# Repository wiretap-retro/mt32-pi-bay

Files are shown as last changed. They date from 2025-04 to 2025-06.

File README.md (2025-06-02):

# mt32-pi-bay
A 5.25" bay panel overlay to control the mt32-pi. 
\
\
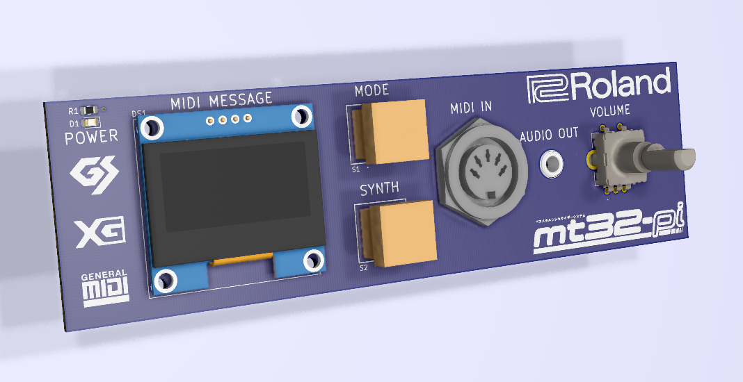
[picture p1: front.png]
front


## Info
The core project design is attributed to Dale Whinham and his awesome mt32-pi project. Repo link: https://github.com/dwhinham/mt32-pi
\
\
This PCB I designed is a 5.25" bay front panel overlay to control the mt32-pi system. It features a power LED, 1.3" OLED, two push buttons, rotary encoder knob, MIDI input jack, and a 3.5mm headphone output jack.
\
\
I have included the full KiCad project along with the Mouser Cart, BOM, and Gerber files for ease of upload.
\
\
This is designed for use with my mt32-pi-zero-breakout project found here: https://github.com/wiretap-retro/mt32-pi-zero-breakout/
\
\
Both the breakout board and 5.25 bay are 100% tested and functional. 

## Parts
The parts in the BOM and Mouser Cart are for building a blue illuminated unit. You can choose other color illuminated components, however you will need to change the resistors to different values since the forward voltage of the LED will be different. Regardless, you should calculate the LED resistors for your desired current/brightness based on the product datasheet curves. The BOM as-is makes the buttons look great, however the power LED is a little bright and could use a slightly higher resistor value.
\
\
Please read the original mt32-pi repository linked in the information section for compatibility of parts if you fork the design or deviate from the chosen parts.

## Assembly
- First solder all the components to the board. To keep the screen low-profile, no pin header socket should be used.
- Solder your wire pigtails to the DIN connector and 3.5mm connector.
- Next, insert the DIN and 3.5mm receptacles into the panel and secure them with the lock nuts.
- Test fit the assembled PCB to the StarTech bay adapter. There are going to be slight interferences from the solder fillets sticking out. Trim the bay adapter with a rotary tool or your preferred cutting method. 
- Clean the StarTech bay panel face and rear side of the PCB with isopropyl alcohol.
- Smear a thin layer of silicone caulk on the StarTech bay panel face.
- Set the PCB onto the bay panel face and apply a small amount of force to allow the caulk to spread and adhere. Shift it around to align it with the edges if necessary. 
- Allow a dry time of 24hrs so the PCB fully cures to the bay adapter face.
- Mount your mt32-pi into the StarTech bay adapter and connect the 2.54mm pitch DuPont connectors to the panel header.

## 1U Case and Parts (optional)
- Athena Power 1U Short-Depth Server Chassis with 5.25" Bay - http://athenapower.com/product/ipc-rackmount-chassis/1u-itx-rackmount/rm-1uc138 (other 1U models may work as well)
- Canakit 3.5A Power Supply - https://www.amazon.com/dp/B07TYQRXTK
- IEC320 Power Connector - https://www.amazon.com/dp/B085BQ3NWD
- SPST Blue Rocker Switch - https://www.amazon.com/dp/B08YN7Z9Y3
- 5V Blue Fans - https://www.amazon.com/dp/B084RCBSBX
- USB to 5V Fan Adapter - https://www.amazon.com/dp/B09HGLN7CX
- USB to DuPont Interal Connectors - https://www.ebay.com/itm/391937393112
- 3D Printable IEC to Flex-ATX adapter - https://www.thingiverse.com/thing:7041659
- 3D Printable Canakit Power Supply Enclosure - https://www.thingiverse.com/thing:7052683

## Finished Product

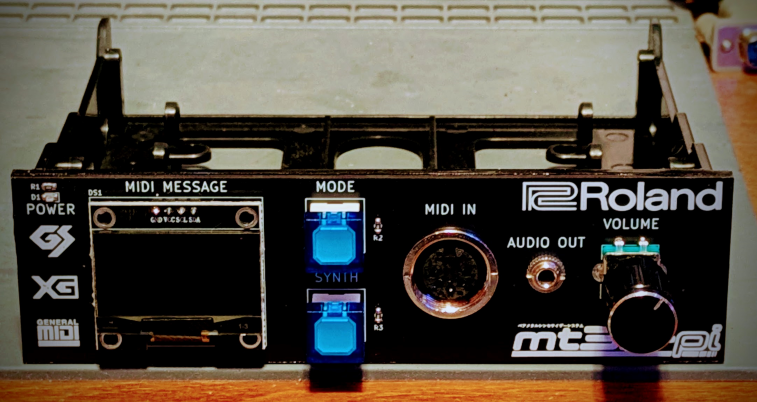
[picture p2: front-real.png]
front2

\
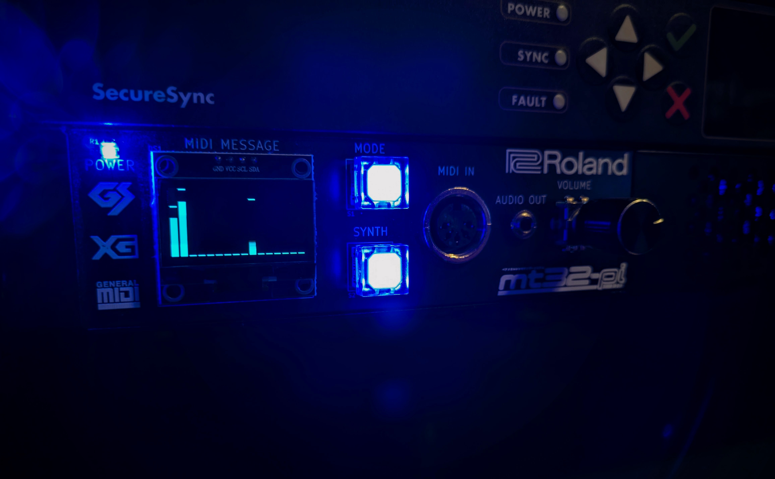
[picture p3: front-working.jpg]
front3

\
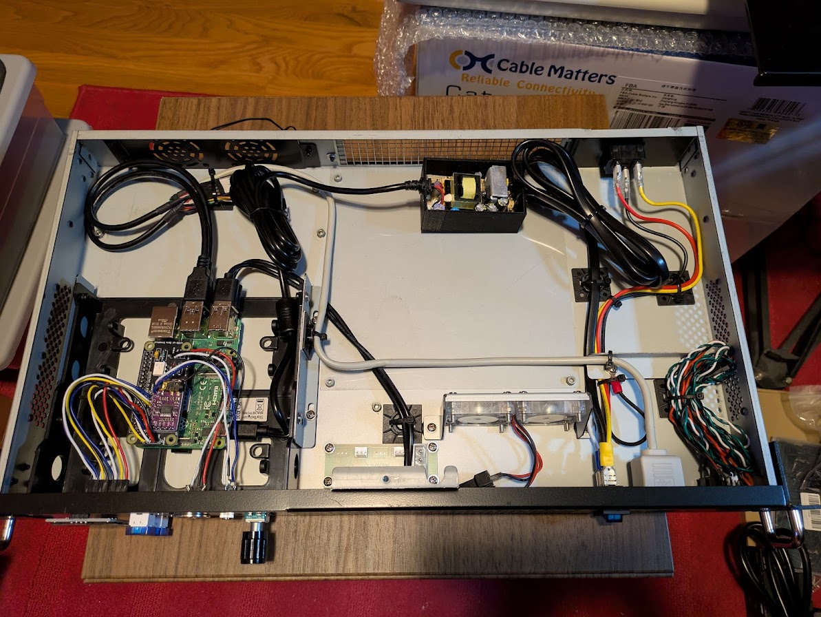
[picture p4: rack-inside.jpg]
front4

\
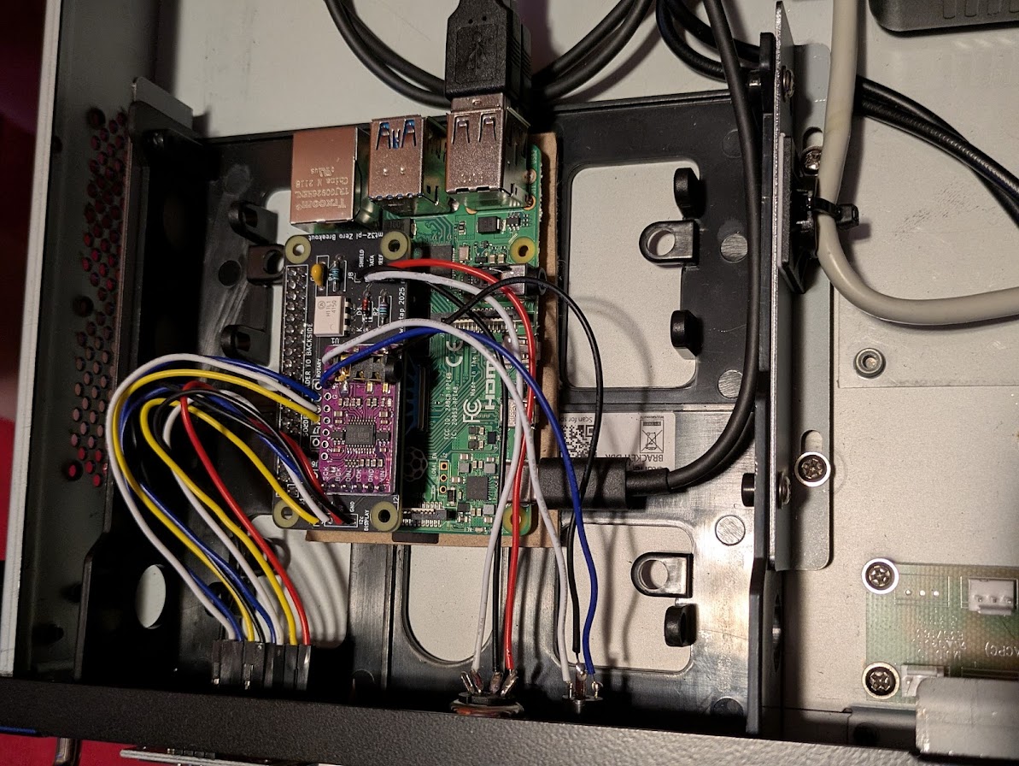
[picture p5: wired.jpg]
front5

\
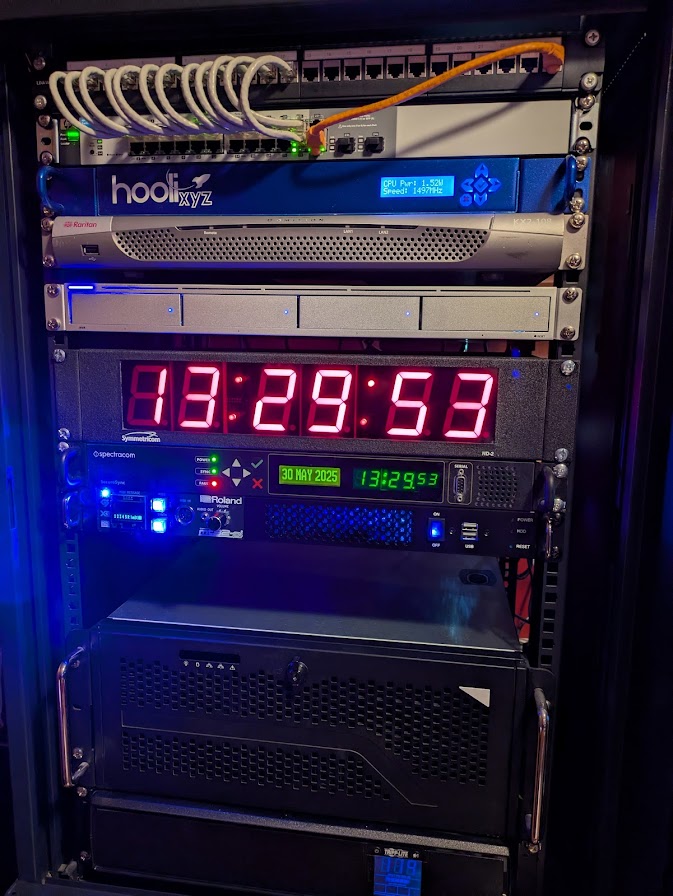
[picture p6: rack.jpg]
front6

\
## Revision Notes
Rev 1 2025-05-28 --- Remapped rotary encoder CW/CCW pins for proper volume up/down when physically turned. \
Rev 0 2025-05-03 --- Cleaned up assembly instructions, added knob to other BOM items section.

## License
This project uses the UNLICENSE. Feel free to do what you want with it. Check over the project before ordering. Build at your own risk.

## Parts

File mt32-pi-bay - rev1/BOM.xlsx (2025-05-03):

mt32-pi 5.25" Bay Device (BLUE LEDs)
Reference | Quantity | Value | Footprint | Description | Manufacturer Name | Part Number | Notes
D1 | 1 | LED_Small | LED_SMD:LED_0805_2012Metric_Pad1.15x1.40mm_HandSolder | 0805 SMD Blue LED | VCC | LSM0805463V | In Mouser Cart
DS1 | 1 | OLED_128X64_1.3_I2C | SamacSys_Parts:LCD_OLED_128X64_1.3_I2C | diymore 1.3" OLED i2c SSH1106 Display | diymore.cc | SKU: 030514LA | Purchase from Ebay/Amazon
IC1 | 1 | EC11E18244A5 | EC11E18244A5 | Encoders 11mm 18 RES 36 DTENT | ALPS Electric | EC11E18244A5 | In Mouser Cart
J1 | 1 | Main Header | Connector_PinHeader_2.54mm:PinHeader_1x09_P2.54mm_Vertical_SMD_Pin1Right | 1x09 2.54mm Pitch SMD Pin Header | Samtec | TSM-109-01-L-SV | In Mouser Cart
R2, R3 | 2 | R_Small | Resistor_SMD:R_0805_2012Metric_Pad1.15x1.40mm_HandSolder | 0805 SMD 75-ohm Resistors | Wurth | 560112120005 | In Mouser Cart
R1 | 1 | R_Small | Resistor_SMD:R_0805_2012Metric_Pad1.15x1.40mm_HandSolder | 0805 SMD 200-ohm Resistors | Wurth | 560112120015 | In Mouser Cart
S1, S2 | 2 | B3W-9010-R1N | B3W9010R1N | Tactile Switches 1 LED RED MILKY WHITE CAP | Omron Electronics | B3W-9010-R1N | In Mouser Cart
MIDI IN | 1 | N/A | Hole | Panel Mount Circular 5P DIN Jack, Female | Same Sky | SD-50LS | In Mouser Cart
AUDIO OUT | 1 | N/A | Hole | Panel Mount 3.5mm TRS Jack, Female | Schurter | 4832.2300 | In Mouser Cart
Mouser Cart Link: | Link (https://www.mouser.com/Tools/Project/Share?AccessID=3359edc1c3)
Other:
Bay Adapter | 1ea | StarTech BRACKETFDBK | Source from Amazon, Ebay, and many other computer stores
Silicone Caulk | 1ea | Clear, small tube | Source from Home Depot, Lowes, Amazon, etc.
Knob | 1ea | 6mm shaft diameter | Source from Ebay, Amazon, Aliexpress.

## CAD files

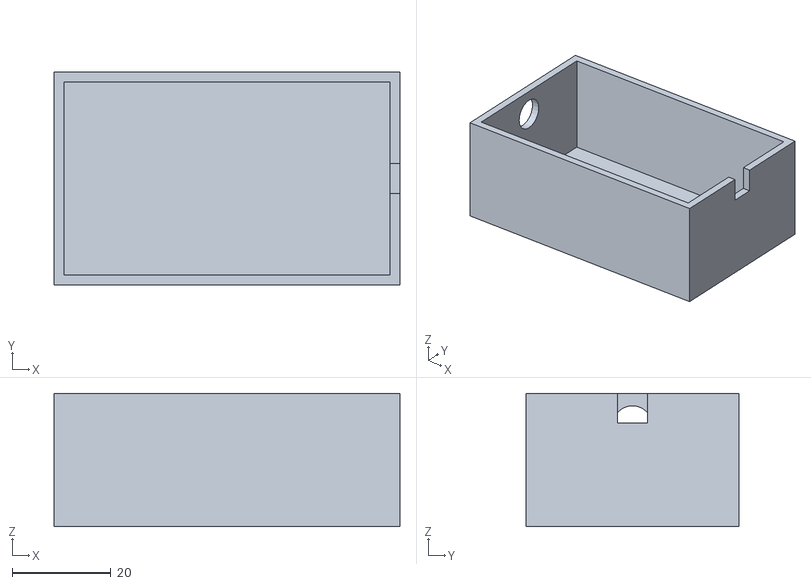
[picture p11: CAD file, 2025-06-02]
STL Files/Canakit DCAR-RSP-3A5C Enclosureuntitled.stl
70.0 x 43.0 x 27.0

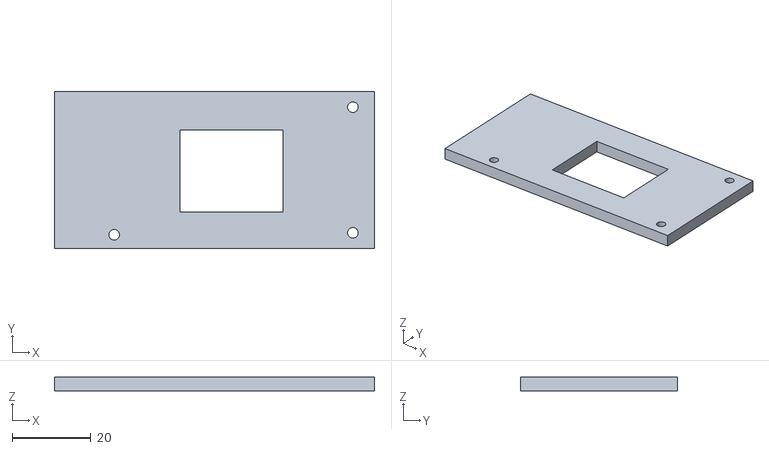
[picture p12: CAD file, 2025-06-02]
STL Files/Flex-ATX plate for FILSHU IEC320.stl
81.5 x 40.0 x 3.50

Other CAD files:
STL Files/Canakit DCAR-RSP-3A5C Enclosure.skp
STL Files/Flex-ATX plate for FILSHU IEC320.skp

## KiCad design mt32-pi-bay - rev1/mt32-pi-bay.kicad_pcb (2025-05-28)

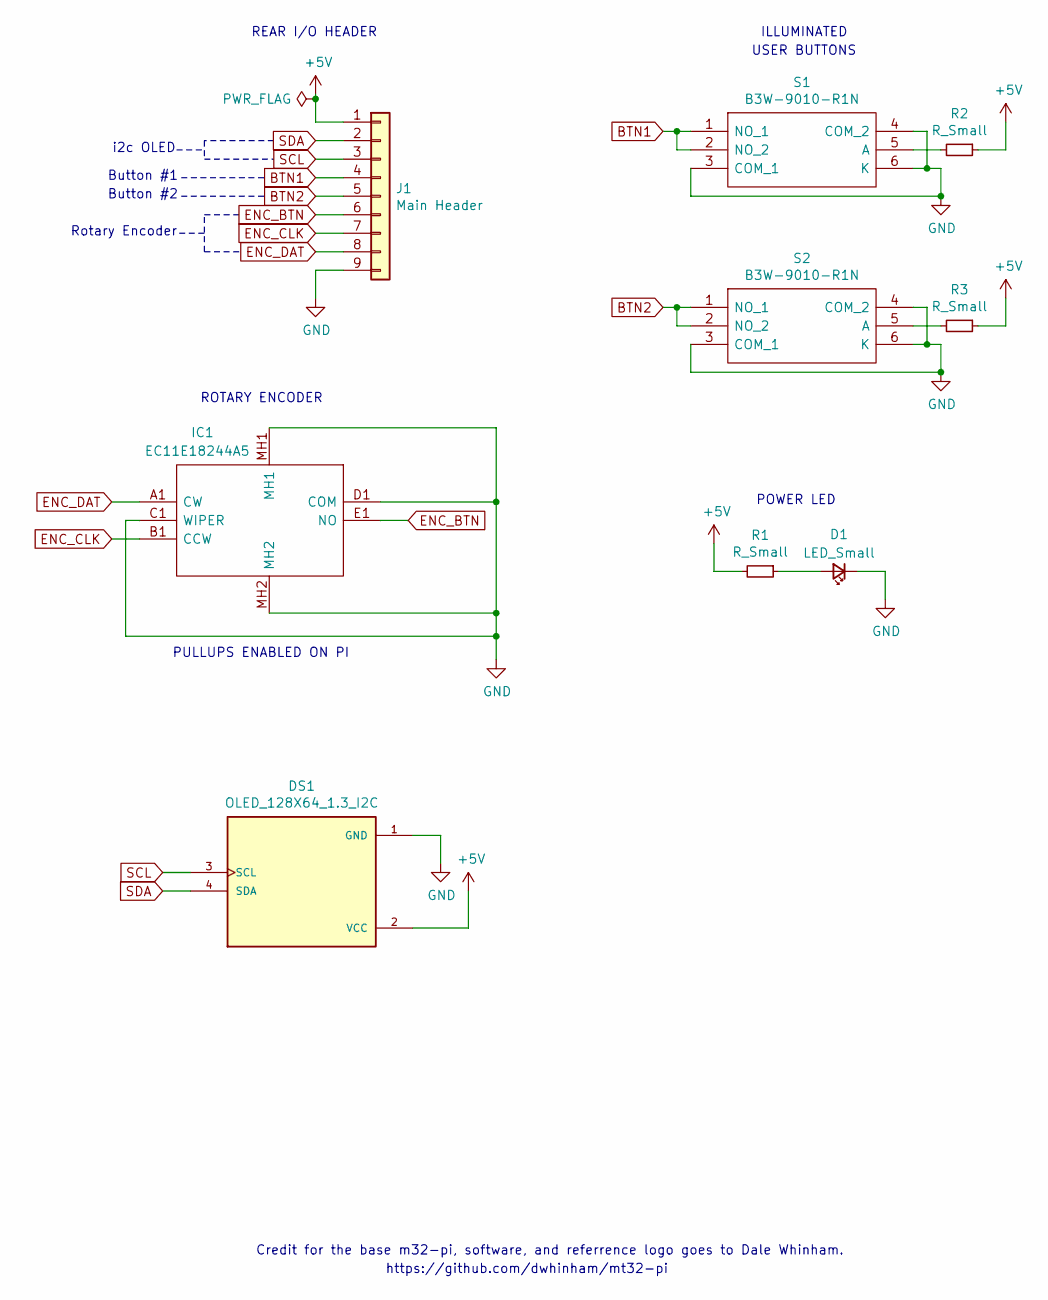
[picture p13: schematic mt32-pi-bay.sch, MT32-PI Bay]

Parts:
D1: LED_Small; LED_0805_2012Metric_Pad1.15x1.40mm_HandSolder
DS1: OLED_128X64_1.3_I2C; LCD_OLED_128X64_1.3_I2C; PARTREV NA
IC1: EC11E18244A5; Mouser Part Number 688-EC11E18244A5
J1: Main Header; PinHeader_1x09_P2.54mm_Vertical_SMD_Pin1Right
R1, R2, R3: R_Small; R_0805_2012Metric_Pad1.15x1.40mm_HandSolder
S1, S2: B3W-9010-R1N; B3W9010R1N; Mouser Part Number 653-B3W-9010-R1N

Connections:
+5V: DS1.2 (VCC), J1.1, R1.2, R2.1, R3.1
BTN1: J1.4, S1.1 (NO_1), S1.2 (NO_2)
BTN2: J1.5, S2.1 (NO_1), S2.2 (NO_2)
ENC_BTN: IC1.E1 (NO), J1.6
ENC_CLK: IC1.B1 (CCW), J1.7
ENC_DAT: IC1.A1 (CW), J1.8
GND: D1.1 (K), DS1.1 (GND), IC1.C1 (WIPER), IC1.D1 (COM), IC1.MH1, IC1.MH2, J1.9, S1.3 (COM_1), S1.4 (COM_2), S1.6 (K), S2.3 (COM_1), S2.4 (COM_2), S2.6 (K)
unnamed: D1.2 (A), R1.1
unnamed: R2.2, S1.5 (A)
unnamed: R3.2, S2.5 (A)
SCL: DS1.3 (SCL), J1.3
SDA: DS1.4 (SDA), J1.2

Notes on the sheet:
i2c OLED
Button #1
Button #2
Rotary Encoder
PULLUPS ENABLED ON PI
ROTARY ENCODER
USER BUTTONS
REAR I/O HEADER
ILLUMINATED
POWER LED
Credit for the base m32-pi, software, and referrence logo goes to Dale Whinham.
https://github.com/dwhinham/mt32-pi

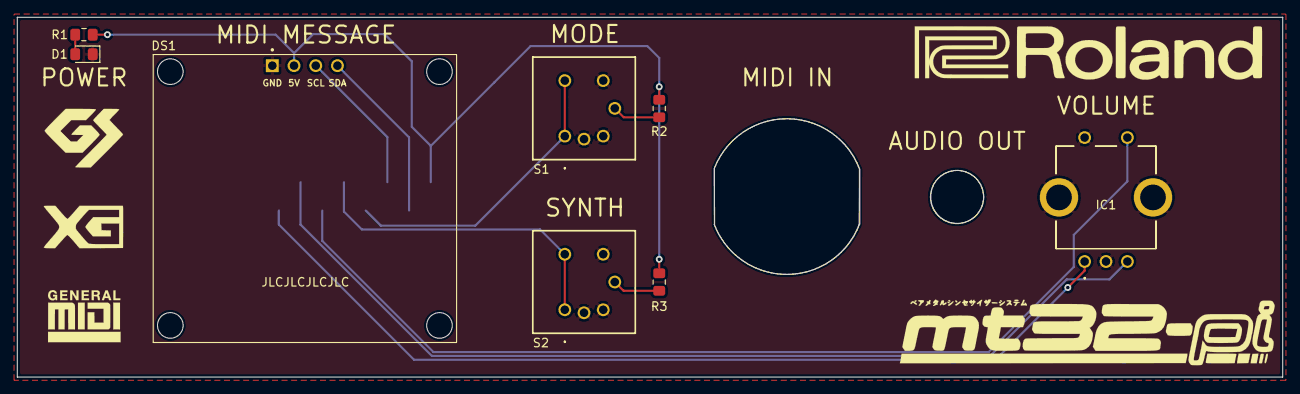
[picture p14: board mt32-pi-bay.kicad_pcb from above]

Board: 2 copper layers, 148.1 x 42.1 mm, 11 parts (1 on the bottom side), 12 nets.

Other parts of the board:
CON1: Same_Sky_SD-LS_DIN5
CON2: Schurter_PG12
